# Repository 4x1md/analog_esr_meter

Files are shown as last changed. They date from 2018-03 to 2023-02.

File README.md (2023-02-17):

# ESR Meter

The schematic of this meter was published in an Italian magazine Nuova Elettronica No. 212.

## Overview

The schematic of this meter was published in an Italian magazine Nuova Elettronica No. 212. I found it more than five years ago on [Talino Tribuzio's IZ7ATH site](http://www.qsl.net/iz7ath/web/02_brew/15_lab/06_esr/index.htm) when I was looking for a simple ESR meter circuit.

## Reference circuits

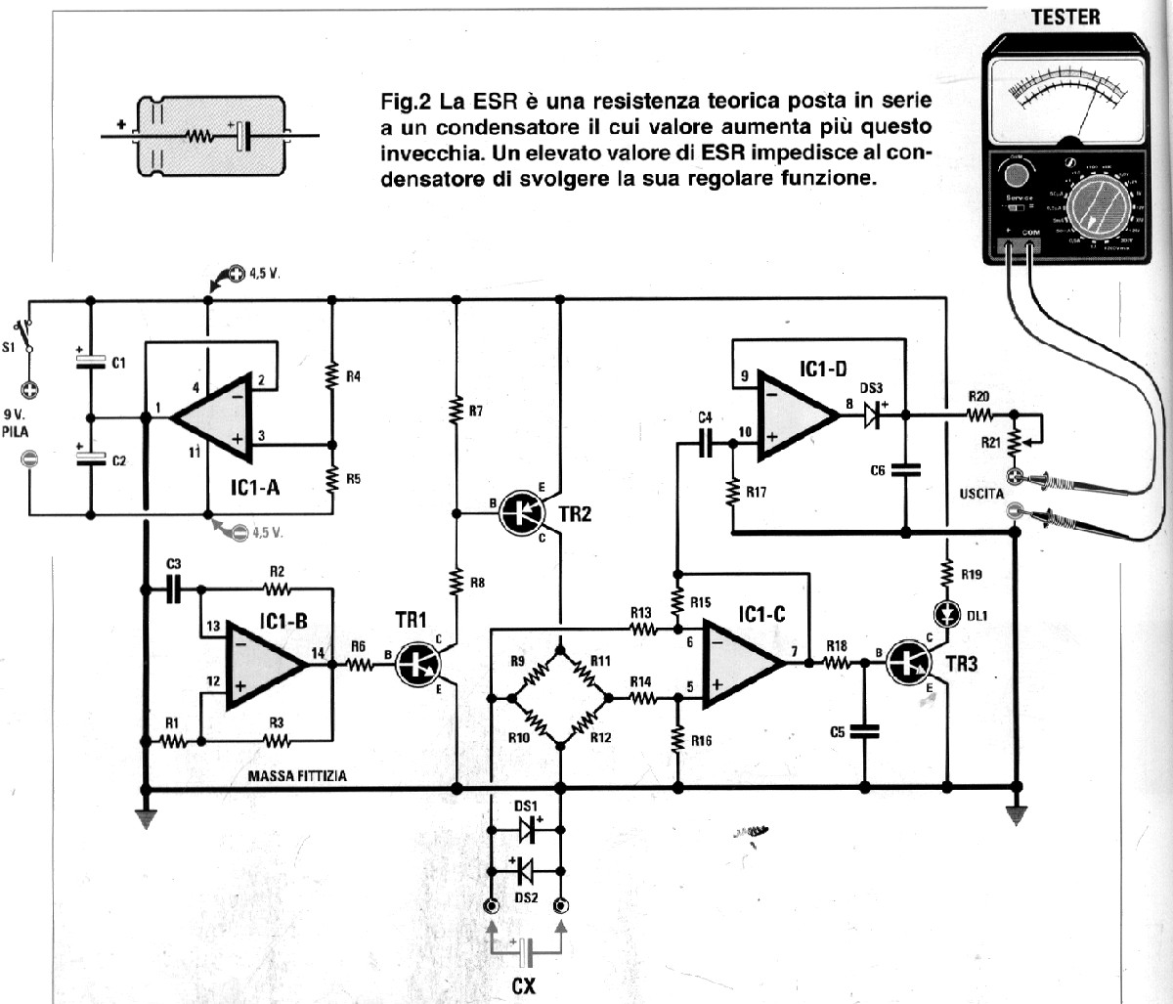
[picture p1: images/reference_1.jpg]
Reference circuit 1


```
R1 = 1.5K
R2,R3,R4,R5 = 10K
R6 = 68K
R7 = 4.7K
R8 = 12K
R9,R11 = 1K 1%
R10,R12 = 22 1%
R13,R14 = 1K
R15,R16,R17 = 47K
R18 = 15K
R19 = 680
R20 = 2.2K
R21 = 20K TRIMMER

C1,C2 = 1uF electrolytic
C3 = 1nF POLY
C4 = 100nFF POLY
C5,C6 = 1uF POLY
DS1, DS2 = 1N4007
DS3 = 1N4148
TR1,TR3 = BC547
TR2 = BC557
IC1 = TL084
```

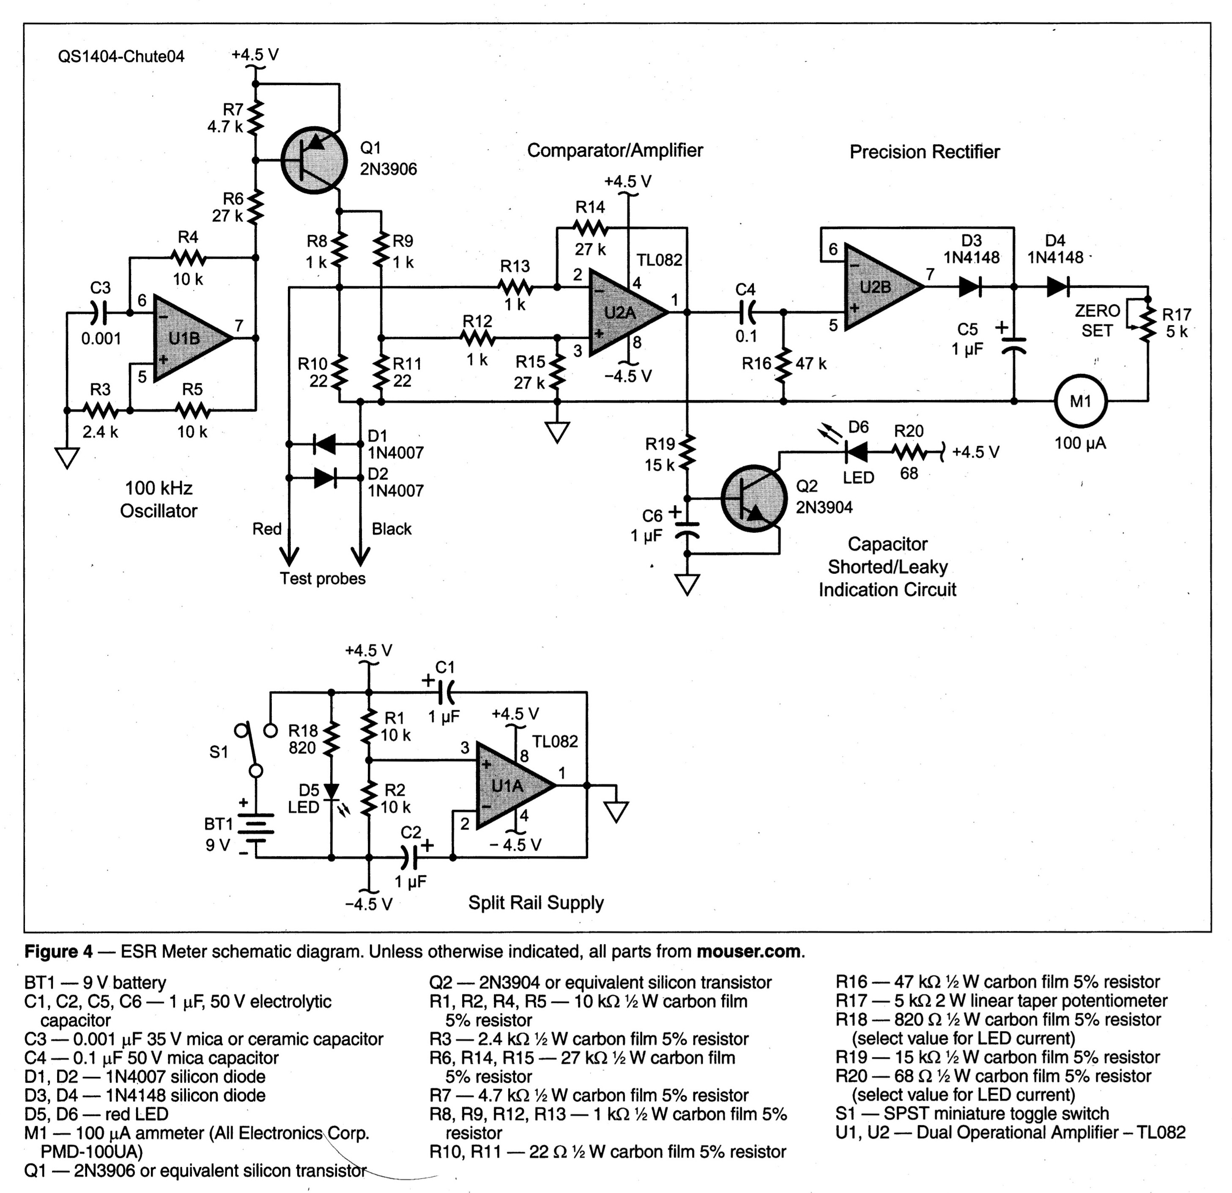
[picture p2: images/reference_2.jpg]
Reference circuit 2


## Project goals

1. Fitting the circuit in an enclosure box.
2. Dual power supply battery and external.

## Schematic

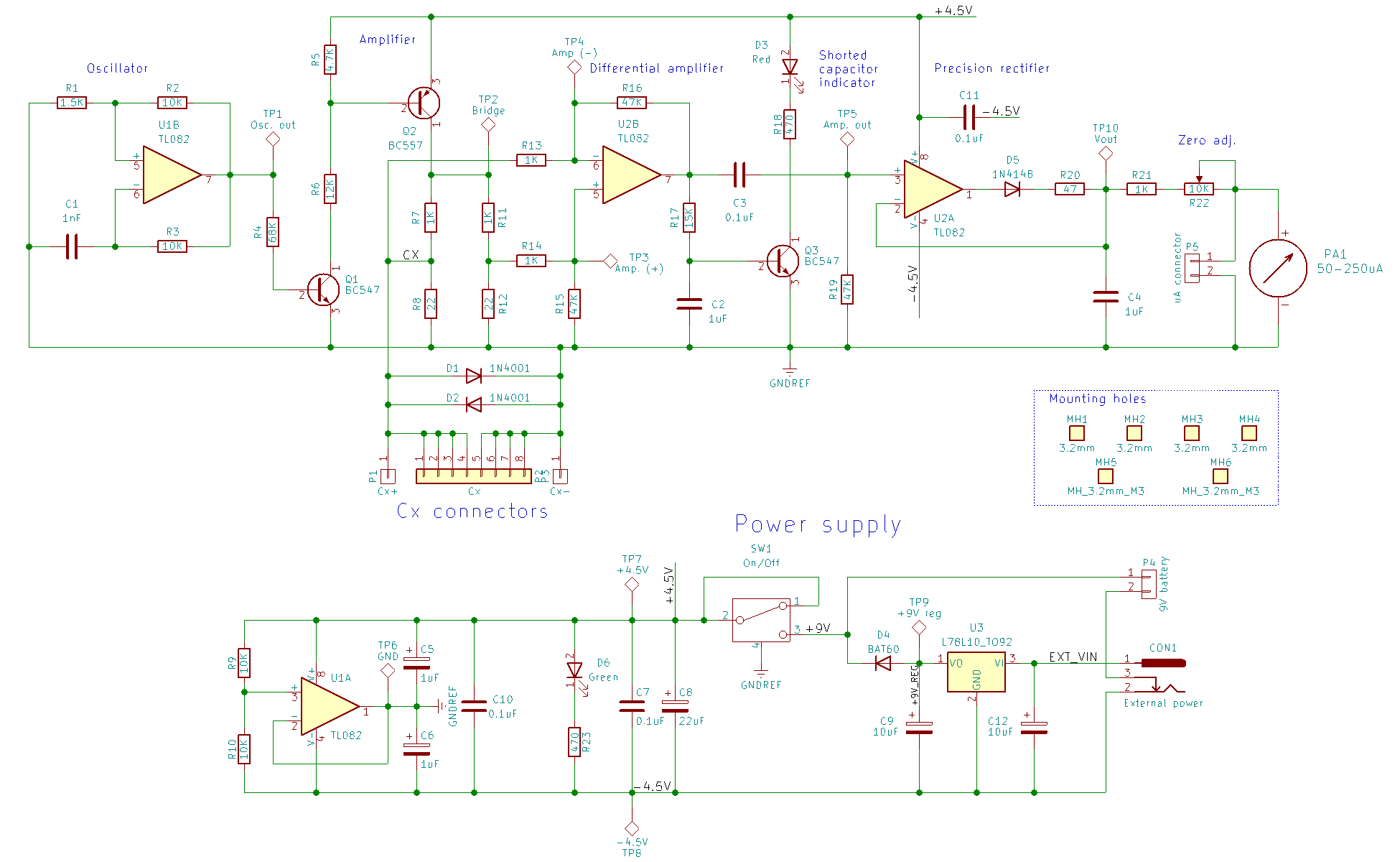
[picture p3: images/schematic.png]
ESR meter circuit rev. A


## Mechanics

A ready available 118x78x33mm plastic box which was purchased on AliExpress. The box is made of a good quality plastic, has enough space for the PCB and a battery compartment.

## PCB

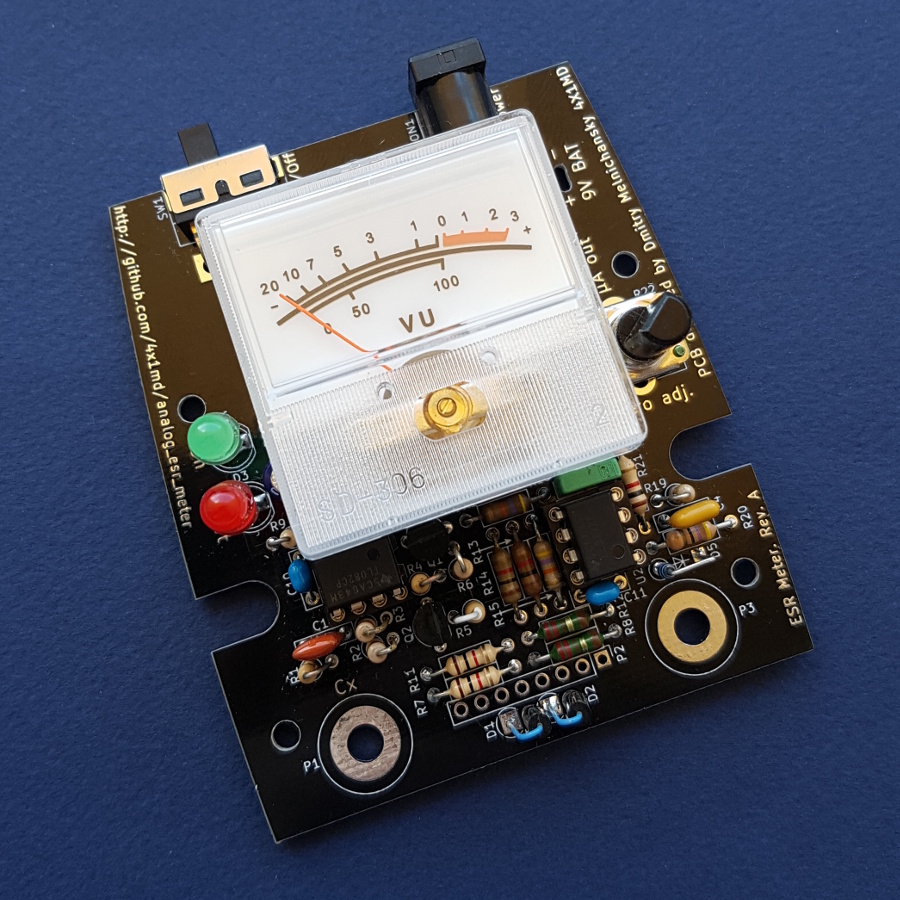
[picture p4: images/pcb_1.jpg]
PCB 1


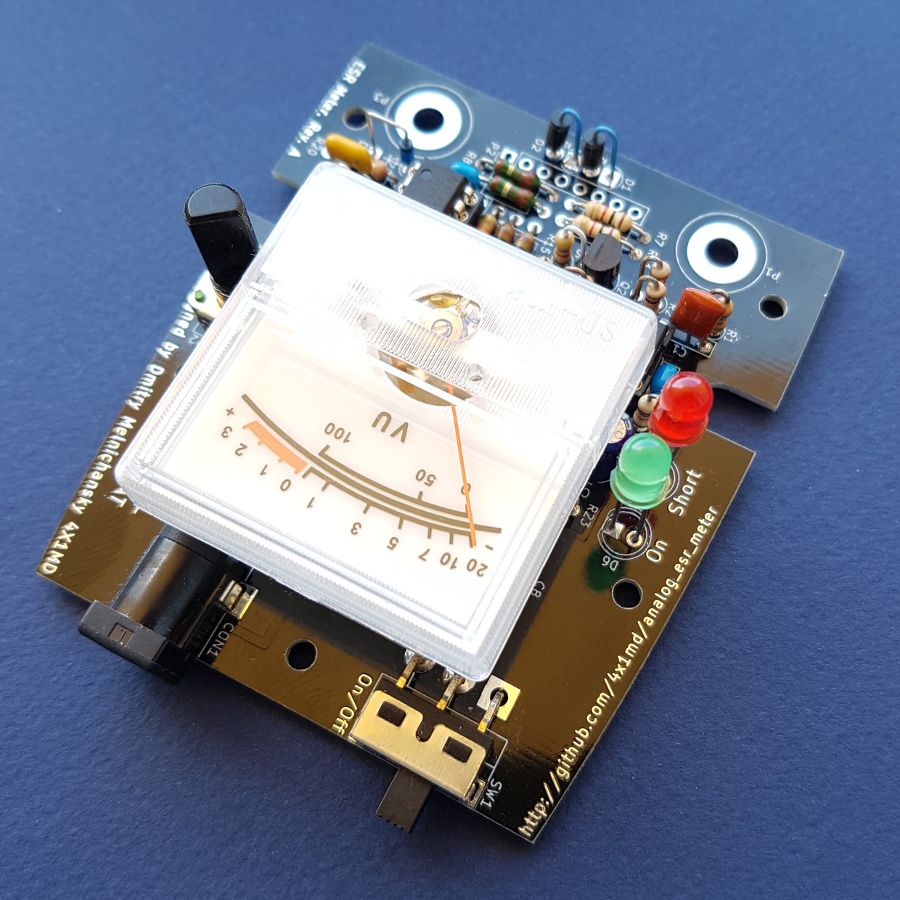
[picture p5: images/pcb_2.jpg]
PCB 2


## Assembled device

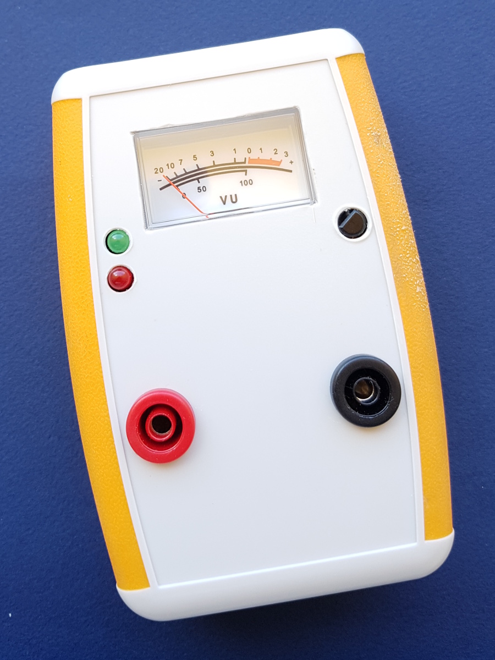
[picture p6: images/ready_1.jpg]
Assembled meter 1


## Alignment

## Links
* http://fillwithgoodthings.blogspot.com/2013/05/esr-meter-schematic.html
* http://kripton2035.free.fr/analog%20esr/esr-poptronix.html
* http://electronics-diy.com/electronic_schematic.php?id=950
* http://www.geocities.jp/shoranosekai/ESR_Tester_Schematic.jpg
* http://ludens.cl/Electron/esr/esr.html
* http://electronics-diy.com/electronic_schematic.php?id=949

## How to Support or Say Thanks

If you like this project, or found here some useful information and want to say thanks, or encourage me to do more, you can buy me a coffee!



"Buy Me A Coffee" (https://www.buymeacoffee.com/4x1md)

You can aslo make a donation with PayPal:



---

**73 de 4X1MD**

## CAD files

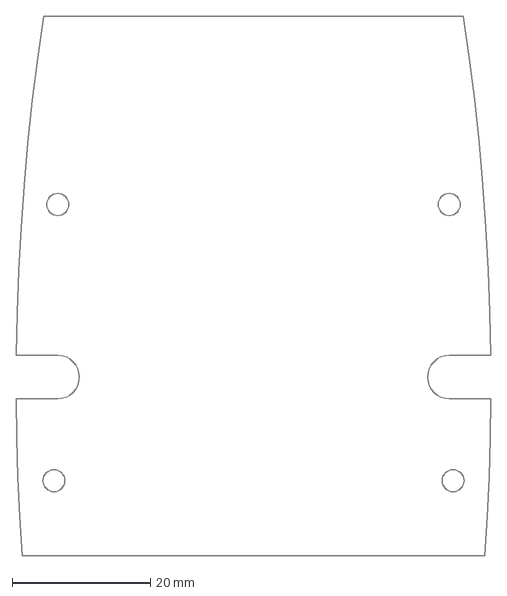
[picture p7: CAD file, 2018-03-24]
mechanics/pcb.dxf
68.7 x 78.2 mm

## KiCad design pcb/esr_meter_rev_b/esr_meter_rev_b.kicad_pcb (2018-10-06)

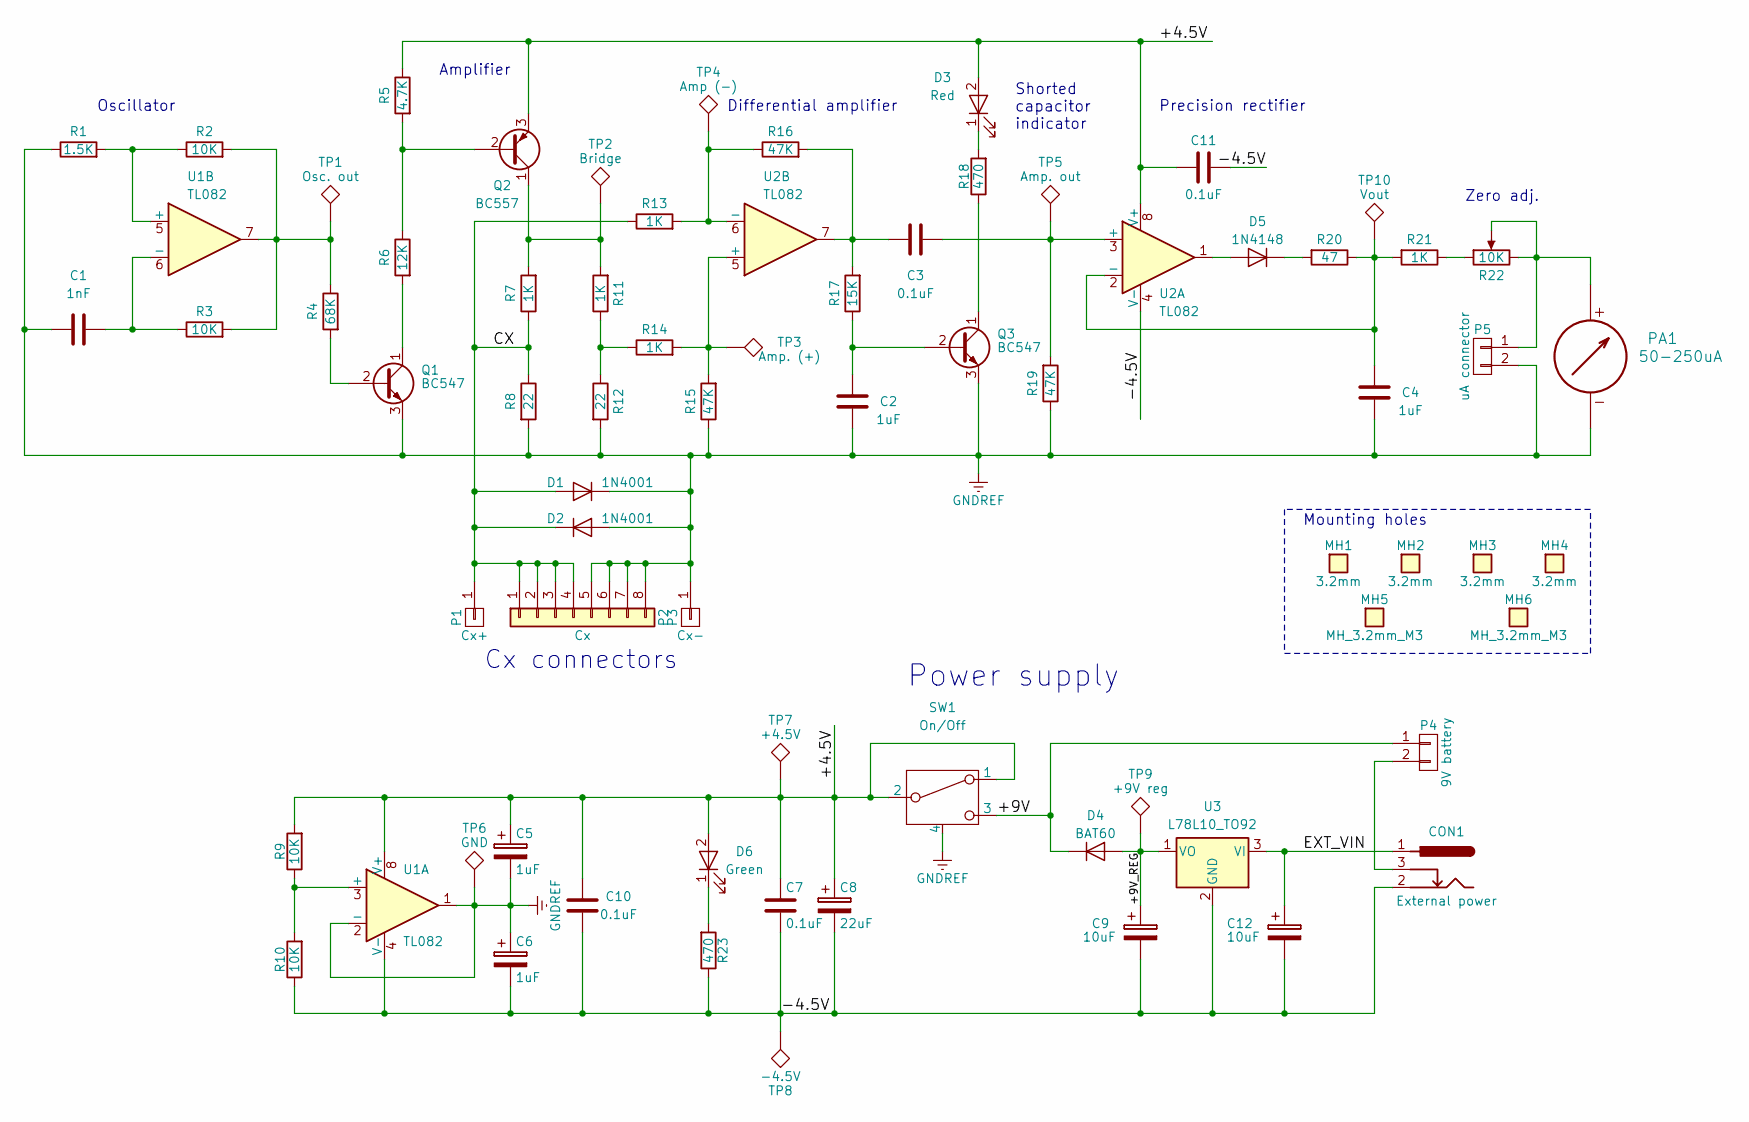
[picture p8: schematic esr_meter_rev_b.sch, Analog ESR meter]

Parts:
C1: 1nF; C_Rect_L7.0mm_W2.0mm_P5.00mm
C2, C4: 1uF; C_Rect_L7.0mm_W2.0mm_P5.00mm
C3, C7, C10, C11: 0.1uF; C_Rect_L7.0mm_W2.0mm_P5.00mm
C5, C6: 1uF; CP_Radial_D5.0mm_P2.50mm
C8: 22uF; CP_Radial_D5.0mm_P2.50mm
C9, C12: 10uF; CP_Radial_D5.0mm_P2.50mm
CON1: External power; BARREL_JACK_PCB_EDGE
D1, D2: 1N4001; D_DO-41_SOD81_P7.62mm_Horizontal
D3: Red; LED_D5.0mm
D4: BAT60; D_DO-35_SOD27_P7.62mm_Horizontal
D5: 1N4148; D_DO-35_SOD27_P5.08mm_Vertical_KathodeUp
D6: Green; LED_D5.0mm
MH1, MH2, MH3, MH4: 3.2mm; MountingHole_3.2mm_M3_Small
MH5, MH6: MH_3.2mm_M3; MountingHole_3.2mm_M3_DIN965
P1: Cx+; Banana_Jack_1Pin
P2: Cx; Socket_Strip_Straight_1x08_Pitch2.54mm
P3: Cx-; Banana_Jack_1Pin
P4: 9V battery; Pin_Header_Straight_1x02_Pitch2.54mm
P5: uA connector; Pin_Header_Straight_1x02_Pitch2.54mm
PA1: 50-250uA; Pin_Header_Straight_1x02_Pitch2.54mm
Q1, Q3: BC547; TO-92_Inline_Wide
Q2: BC557; TO-92_Inline_Wide
R1: 1.5K; R_Axial_DIN0207_L6.3mm_D2.5mm_P2.54mm_Vertical
R2, R3, R9, R10: 10K; R_Axial_DIN0207_L6.3mm_D2.5mm_P2.54mm_Vertical
R4: 68K; R_Axial_DIN0207_L6.3mm_D2.5mm_P2.54mm_Vertical
R5: 4.7K; R_Axial_DIN0207_L6.3mm_D2.5mm_P2.54mm_Vertical
R6: 12K; R_Axial_DIN0207_L6.3mm_D2.5mm_P2.54mm_Vertical
R7, R11, R13, R14, R21: 1K; R_Axial_DIN0207_L6.3mm_D2.5mm_P10.16mm_Horizontal
R8, R12: 22; R_Axial_DIN0207_L6.3mm_D2.5mm_P10.16mm_Horizontal
R15, R16: 47K; R_Axial_DIN0207_L6.3mm_D2.5mm_P10.16mm_Horizontal
R17: 15K; R_Axial_DIN0207_L6.3mm_D2.5mm_P10.16mm_Horizontal
R18, R23: 470; R_Axial_DIN0207_L6.3mm_D2.5mm_P10.16mm_Horizontal
R19: 47K; R_Axial_DIN0207_L6.3mm_D2.5mm_P2.54mm_Vertical
R20: 47; R_Axial_DIN0207_L6.3mm_D2.5mm_P10.16mm_Horizontal
R22: 10K; Potentiometer_Alps_RK09K_Horizontal
SW1: On/Off; Switch_Slide_SPDT_THT_5MS1S102AM6QES
TP1: Osc. out; Measurement_Point_Round-SMD-Pad_Small
TP2: Bridge; Measurement_Point_Round-SMD-Pad_Small
TP3: Amp. (+); Measurement_Point_Round-SMD-Pad_Small
TP4: Amp (-); Measurement_Point_Round-SMD-Pad_Small
TP5: Amp. out; Measurement_Point_Round-SMD-Pad_Small
TP6: GND; Measurement_Point_Round-SMD-Pad_Small
TP7: +4.5V; Measurement_Point_Round-SMD-Pad_Small
TP8: -4.5V; Measurement_Point_Round-SMD-Pad_Small
TP9: +9V reg; Measurement_Point_Round-SMD-Pad_Small
TP10: Vout; Measurement_Point_Round-SMD-Pad_Small
U1, U2: TL082; DIP-8_W7.62mm
U3: L78L10_TO92; TO-92_Inline_Wide

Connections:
/+4.5V: C5.1, C7.1, C8.1, C10.1, C11.1, D3.2 (A), D6.2 (A), Q2.3 (E), R5.1, R9.2, SW1.1, SW1.2, TP7.1, U1.8 (V+), U2.8 (V+); also elsewhere on the board
/+9V: D4.1 (K), P4.1, SW1.3
/+9V_REG: C9.1, D4.2 (A), TP9.1, U3.1 (VO)
/-4.5V: C6.2, C7.2, C8.2, C9.2, C10.2, C11.2, C12.2, CON1.2, R10.1, R23.1, TP8.1, U1.4 (V-), U2.4 (V-), U3.2 (GND)
/CX: D1.2 (A), D2.1 (K), P1.1, P2.1, P2.2, P2.3, P2.4, R7.1, R8.1, R13.1
/EXT_VIN: C12.1, CON1.1, U3.3 (VI)
GNDREF: C1.2, C2.2, C4.2, C5.2, C6.1, D1.1 (K), D2.2 (A), P2.5, P2.6, P2.7, P2.8, P3.1, P5.2, PA1.2 (-), Q1.3 (E), Q3.3 (E), R1.1, R8.2, R12.2, R15.1, R19.1, SW1.4, TP6.1, U1.1, U1.2 (-)
unnamed: C1.1, R3.1, U1.6 (-)
unnamed: C2.1, Q3.2 (B), R17.1
unnamed: C3.1, R16.2, R17.2, U2.7
unnamed: C3.2, R19.2, TP5.1, U2.3 (+)
unnamed: C4.1, R20.1, R21.2, TP10.1, U2.2 (-)
unnamed: CON1.3, P4.2
unnamed 13: D3.1 (K), R18.2; also elsewhere on the board
unnamed: D5.1 (K), R20.2
unnamed: D5.2 (A), U2.1
unnamed 16: D6.1 (K), R23.2; also elsewhere on the board
unnamed 17: P5.1, PA1.1 (+), R22.2, R22.3; also elsewhere on the board
unnamed: Q1.1 (C), R6.2
unnamed: Q1.2 (B), R4.2
unnamed: Q2.1 (C), R7.2, R11.2, TP2.1
unnamed: Q2.2 (B), R5.2, R6.1
unnamed: Q3.1 (C), R18.1
unnamed: R1.2, R2.1, U1.5 (+)
unnamed: R2.2, R3.2, R4.1, TP1.1, U1.7
unnamed: R9.1, R10.2, U1.3 (+)
unnamed: R11.1, R12.1, R14.1
unnamed: R13.2, R16.1, TP4.1, U2.6 (-)
unnamed: R14.2, R15.2, TP3.1, U2.5 (+)
unnamed 29: R21.1, R22.1; also elsewhere on the board

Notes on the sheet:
Power supply
Oscillator
Differential amplifier
Cx connectors
Amplifier
Shorted capacitor indicator
Zero adj.
Precision rectifier
Mounting holes

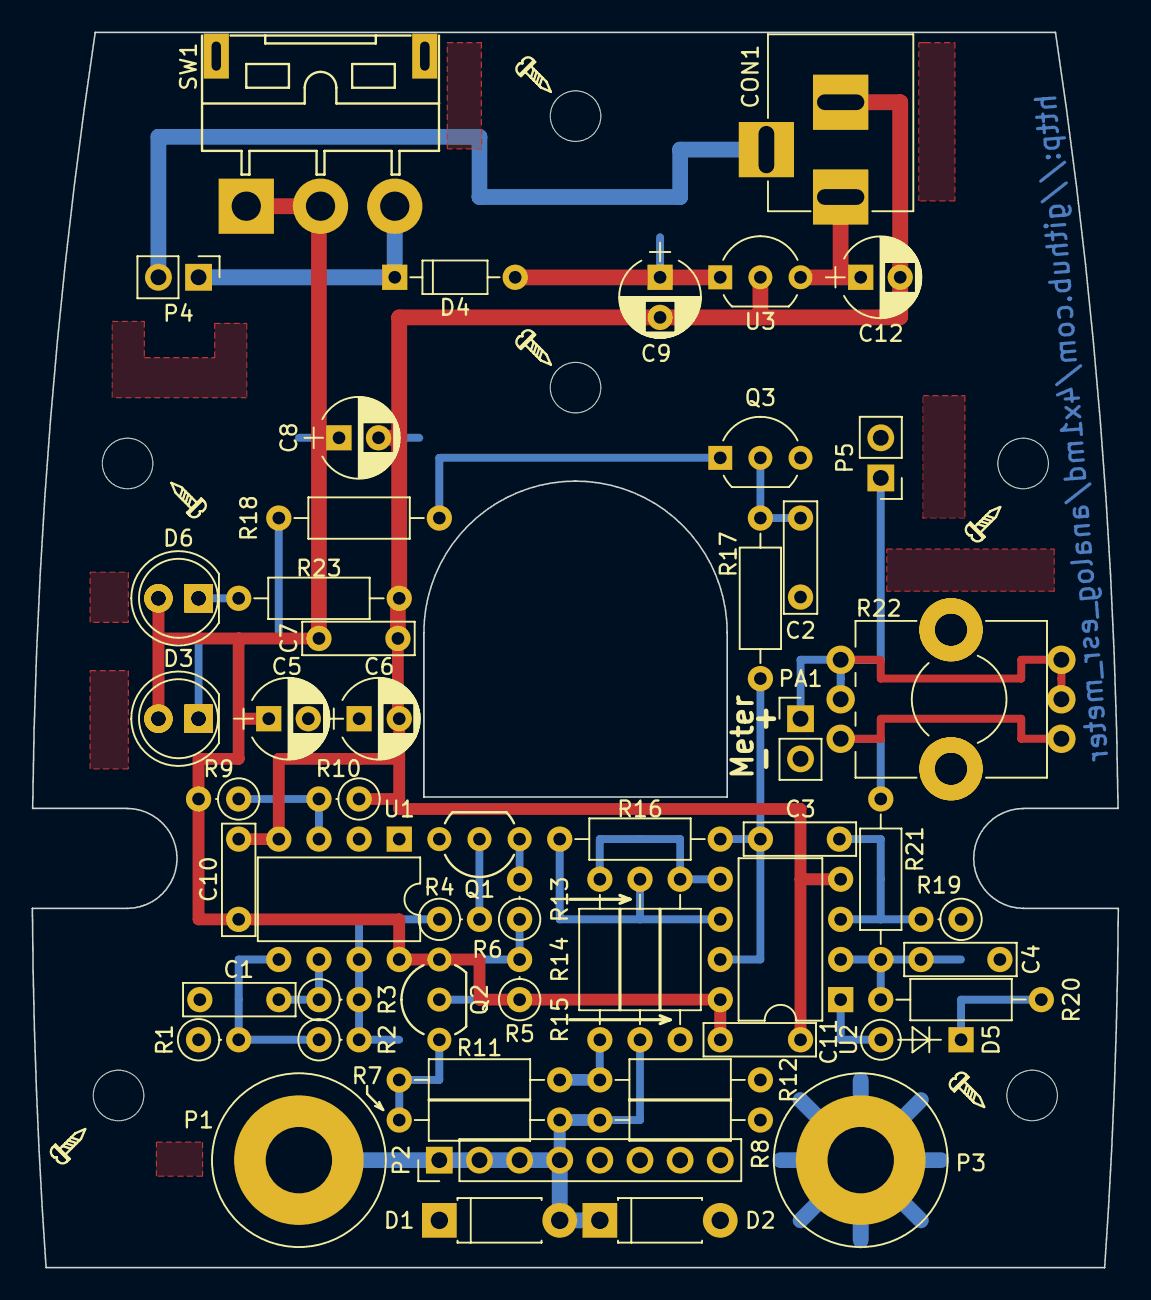
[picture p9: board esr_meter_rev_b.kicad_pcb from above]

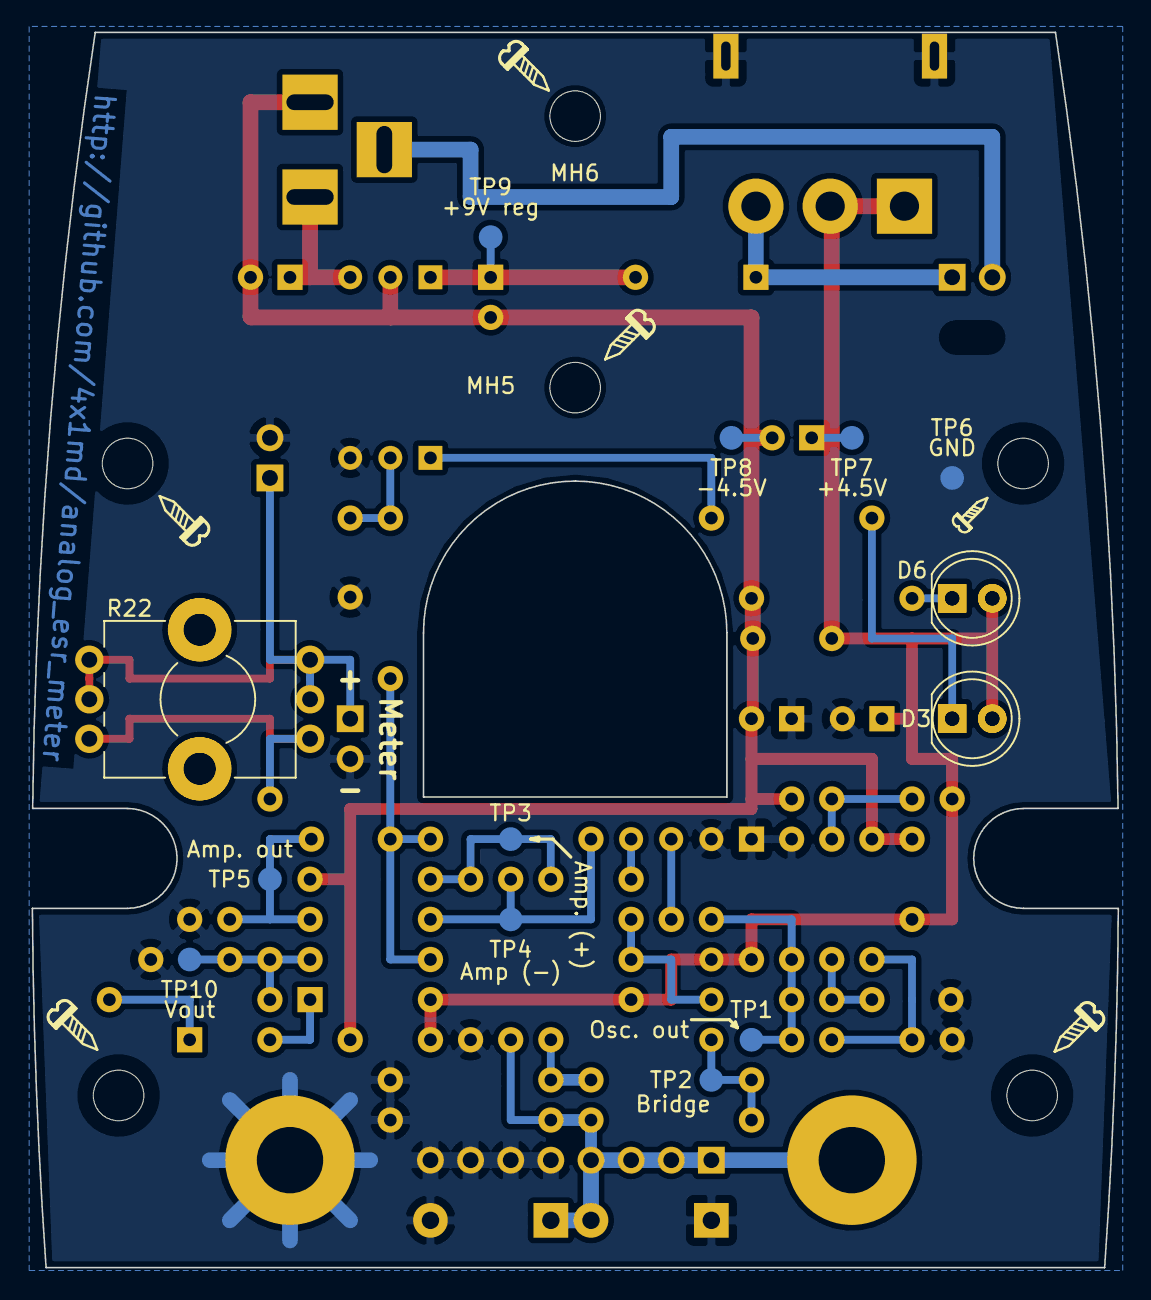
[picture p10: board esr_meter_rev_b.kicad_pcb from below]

Board: 2 copper layers, 68.7 x 78.2 mm, 75 parts (13 on the bottom side), 30 nets.

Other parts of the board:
D3#2: Red; LED_D5.0mm
D6#2: Green; LED_D5.0mm
MH**: 1.5mmx3.2mm_hole_for_wires
R22#2: 10K; Potentiometer_Alps_RK09K_Horizontal

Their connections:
/+4.5V: D3#2.2, D6#2.2; also elsewhere on the board
unnamed 13: D3#2.1; also elsewhere on the board
unnamed 16: D6#2.1; also elsewhere on the board
unnamed 17: R22#2.2, R22#2.3; also elsewhere on the board
unnamed 29: R22#2.1; also elsewhere on the board

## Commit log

2018-03-10 PCB revision A.
    [esr_meter_rev_a-B.Cu.gbr, esr_meter_rev_a-B.Mask.gbr, esr_meter_rev_a-B.SilkS.gbr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]
2018-03-24 PCB mechanical drawing.
    [pcb.dxf]
2018-09-01 Revison B: KiCAD 4.0 project and gerbers.
    [esr_meter_rev_b-B.Cu.gbr, esr_meter_rev_b-B.Mask.gbr, esr_meter_rev_b-B.SilkS.gbr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]
2018-09-29 Cosmetic changes to PCB.
    [esr_meter_rev_b.kicad_pcb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]
2018-10-06 Corrected silkprints.
    [esr_meter_rev_b-B.Cu.gbr, esr_meter_rev_b-B.Mask.gbr, esr_meter_rev_b-B.SilkS.gbr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]
2019-01-25 Minor update.
    [esr_meter_rev_b.sch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]
